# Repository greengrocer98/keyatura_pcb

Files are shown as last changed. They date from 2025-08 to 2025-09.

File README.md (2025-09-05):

# KEYATURA
Keyatura (/ˌkeɪ.əˈtʊə.rə/) - 36-key ergonomic keyboard with MX-spacing and support of choc_v2v1/MX switches.

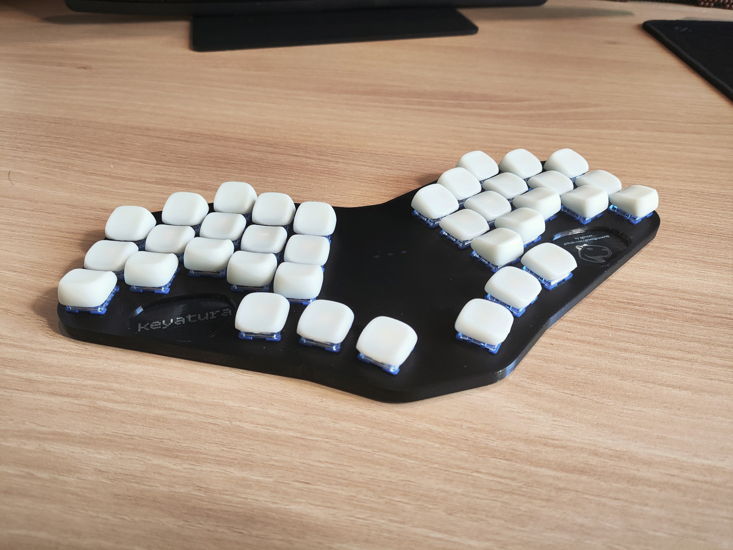
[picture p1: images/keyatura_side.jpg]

### Features
* Promicro compatible MCU
* Hotswap for choc/MX
* Three led indicators
* Mill-Max hotswap sockets for MCU
* Power switch
* Reset button
### PCB
#### <div align="center">Top<div>
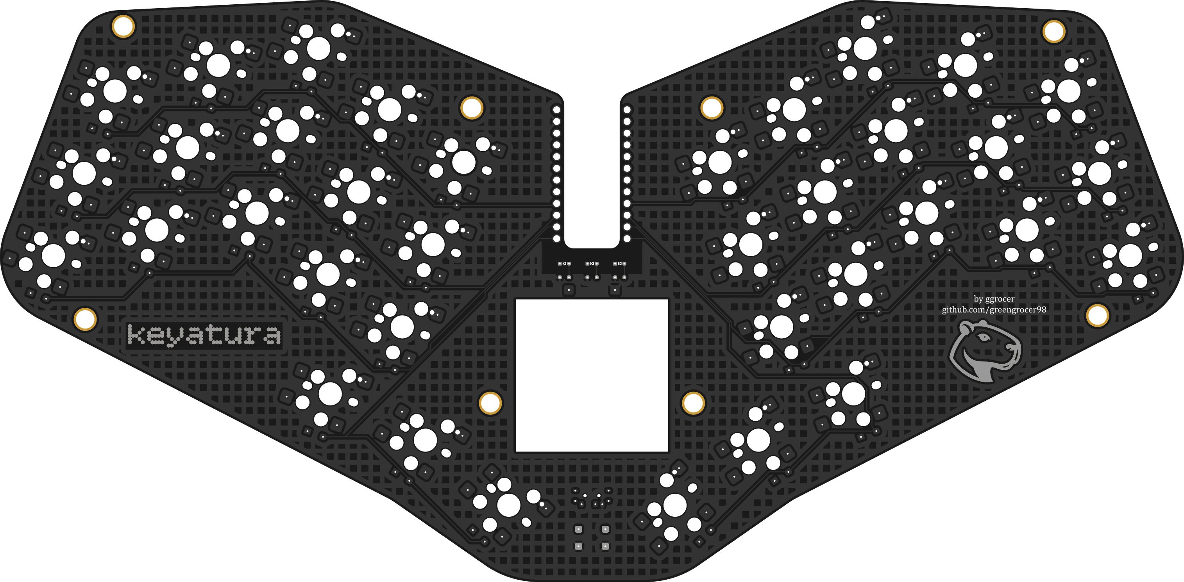
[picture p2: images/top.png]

#### <div align="center">Bottom<div>
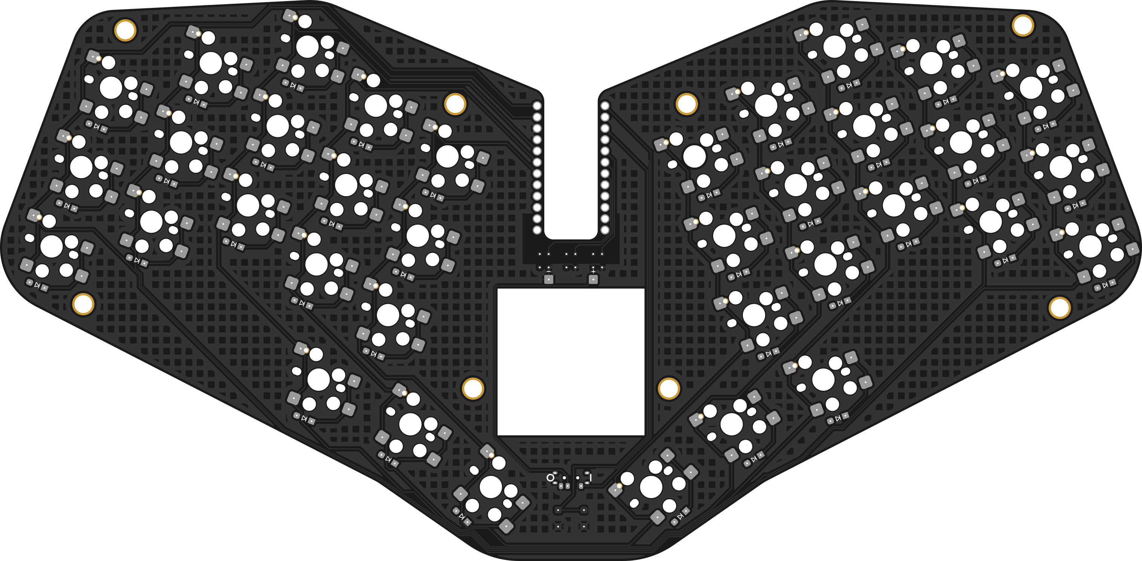
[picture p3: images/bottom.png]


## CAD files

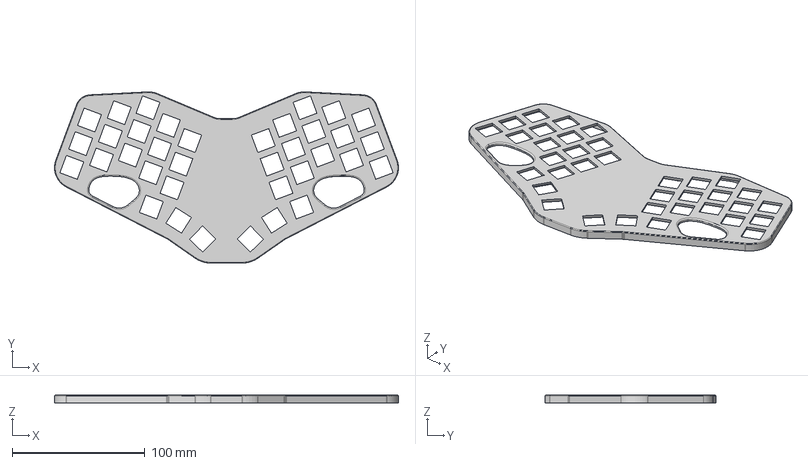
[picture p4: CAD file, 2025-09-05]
3d files/top plate.step
259.5 x 129.2 x 5.80 mm

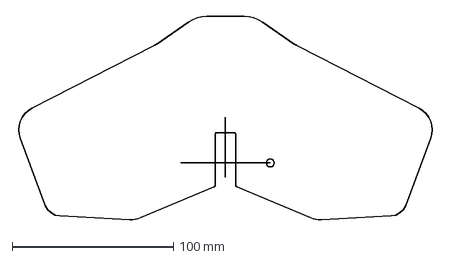
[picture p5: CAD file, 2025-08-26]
kicad/keyatura/outline_v2.dxf
259.9 x 126.3 mm

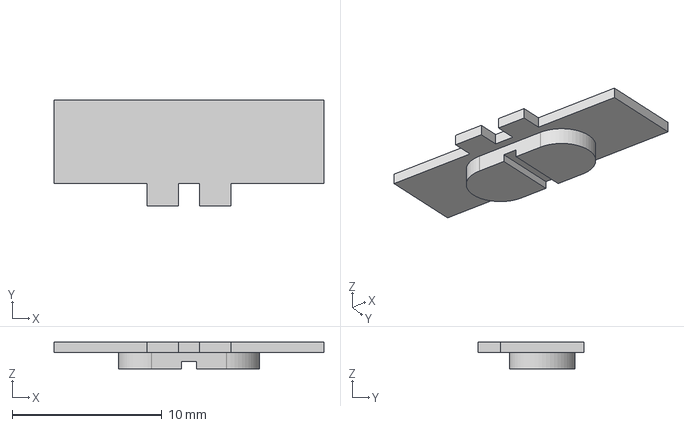
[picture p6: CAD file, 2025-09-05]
3d files/switch slicer.step
18.0 x 7.10 x 1.80 mm

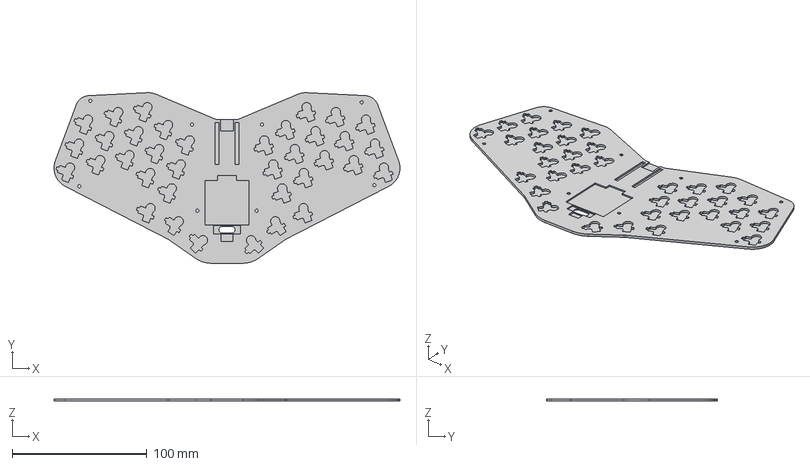
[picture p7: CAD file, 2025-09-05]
3d files/bottom plate.step
257.2 x 126.9 x 1.80 mm

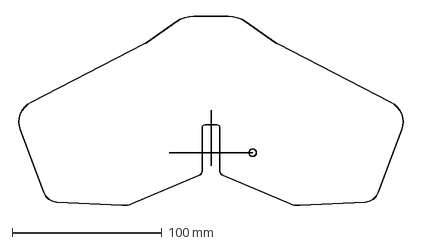
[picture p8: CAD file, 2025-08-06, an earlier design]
kicad/keyatura/outline.dxf
259.9 x 126.3 mm

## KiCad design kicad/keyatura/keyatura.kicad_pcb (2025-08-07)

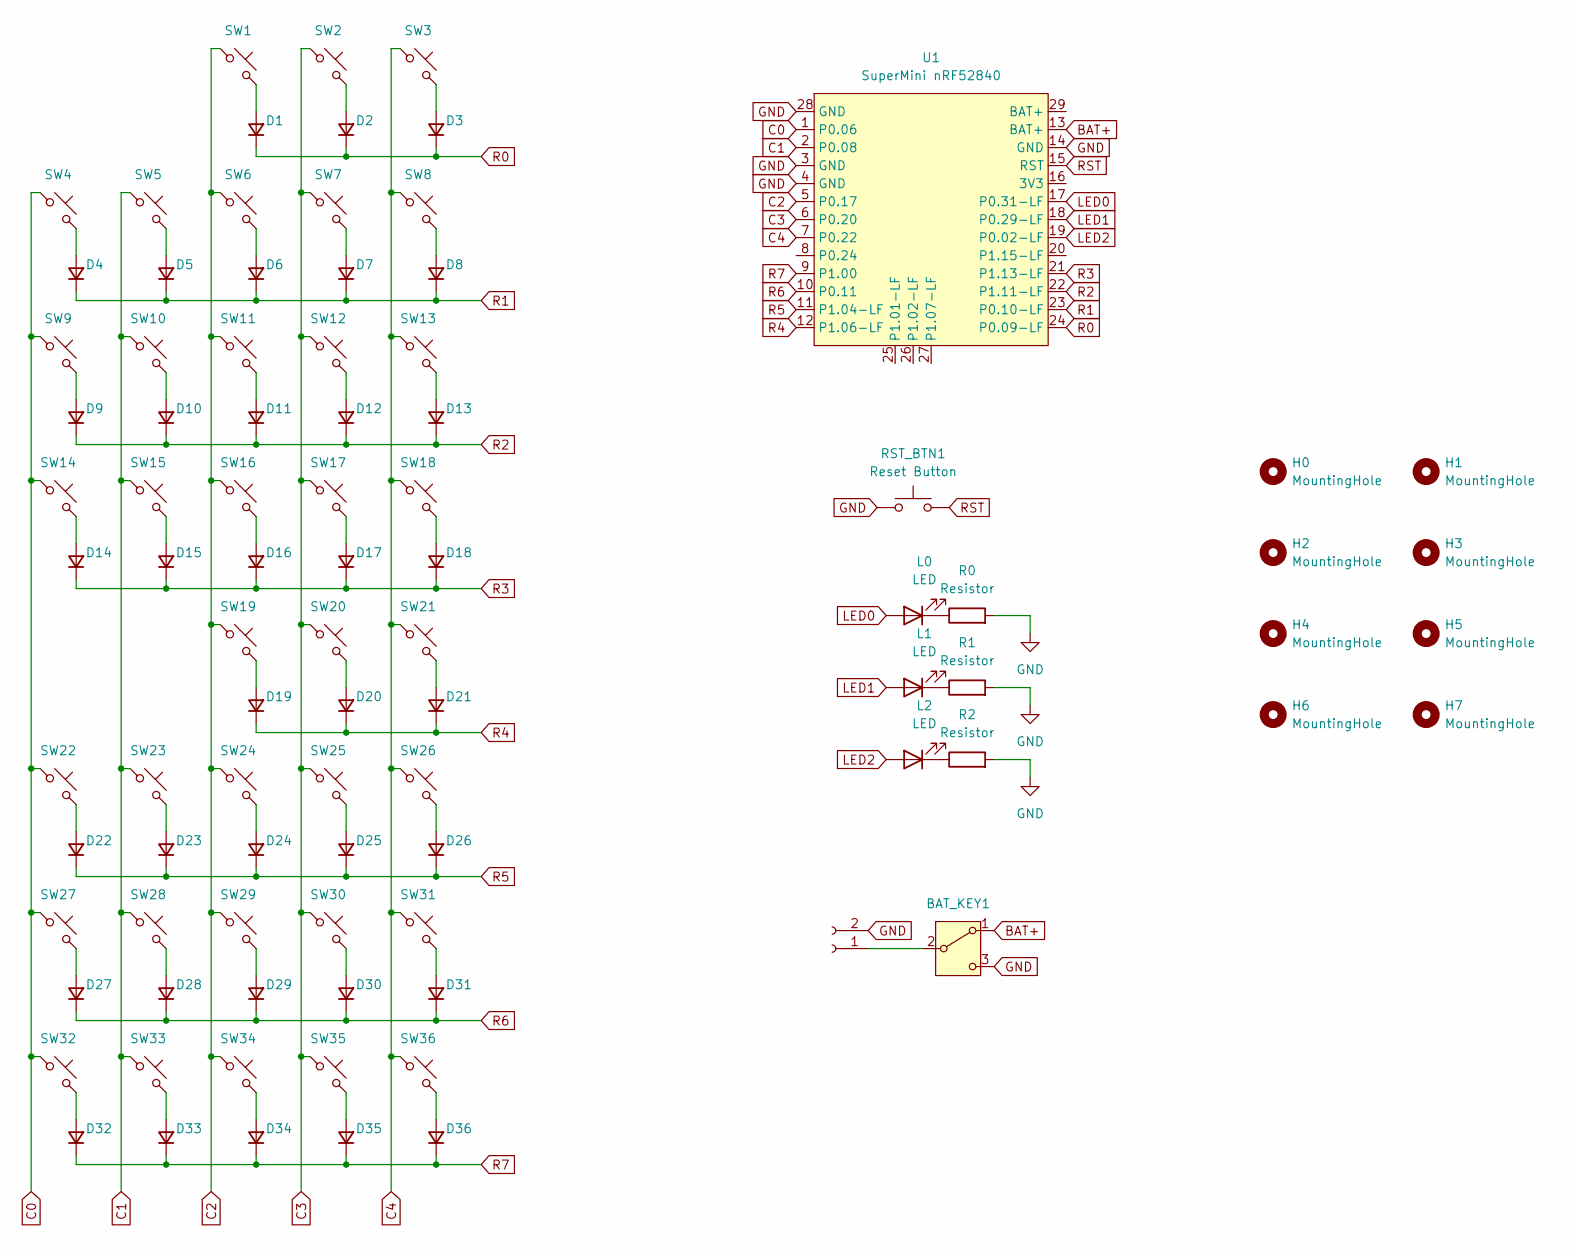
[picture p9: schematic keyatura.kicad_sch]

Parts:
BAT_KEY1: SW_SPDT; MSK-12C02
D1, D2, D3, D4, D5, D6, D7, D8, D9, D10, D11, D12, D13, D14, D15, D16, D17, D18, D19, D20, D21, D22, D23, D24, D25, D26, D27, D28, D29, D30, D31, D32, D33, D34, D35, D36: D; diode
H0, H1, H2, H3, H4, H5, H6, H7: MountingHole; mounting hole
J1: Battery; battery
L0, L1, L2: LED
R0, R1, R2: Resistor; resistor
RST_BTN1: Reset Button; reset button
SW1, SW2, SW3, SW4, SW5, SW6, SW7, SW8, SW9, SW10, SW11, SW12, SW13, SW14, SW15, SW16, SW17, SW18, SW19, SW20, SW21, SW22, SW23, SW24, SW25, SW26, SW27, SW28, SW29, SW30, SW31, SW32, SW33, SW34, SW35, SW36: SW_Push; SW_MX_Kailh_Choc_V1V2_HotSwap_Hybrid
U1: SuperMini nRF52840; supermini

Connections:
BAT+: BAT_KEY1.1 (A), U1.13 (BAT+)
C0: SW4.1, SW9.1, SW14.1, SW22.1, SW27.1, SW32.1, U1.1 (P0.06)
C1: SW5.1, SW10.1, SW15.1, SW23.1, SW28.1, SW33.1, U1.2 (P0.08)
C2: SW1.1, SW6.1, SW11.1, SW16.1, SW19.1, SW24.1, SW29.1, SW34.1, U1.5 (P0.17)
C3: SW2.1, SW7.1, SW12.1, SW17.1, SW20.1, SW25.1, SW30.1, SW35.1, U1.6 (P0.20)
C4: SW3.1, SW8.1, SW13.1, SW18.1, SW21.1, SW26.1, SW31.1, SW36.1, U1.7 (P0.22)
GND: BAT_KEY1.3 (C), J1.2, R0.2, R1.2, R2.2, RST_BTN1.1, U1.3 (GND), U1.4 (GND), U1.14 (GND), U1.28 (GND)
LED0: L0.2 (A), U1.17 (P0.31-LF)
LED1: L1.2 (A), U1.18 (P0.29-LF)
LED2: L2.2 (A), U1.19 (P0.02-LF)
unnamed: BAT_KEY1.2 (B), J1.1
unnamed: D1.2 (A), SW1.2
unnamed: D2.2 (A), SW2.2
unnamed: D3.2 (A), SW3.2
unnamed: D4.2 (A), SW4.2
unnamed: D5.2 (A), SW5.2
unnamed: D6.2 (A), SW6.2
unnamed: D7.2 (A), SW7.2
unnamed: D8.2 (A), SW8.2
unnamed: D9.2 (A), SW9.2
unnamed: D10.2 (A), SW10.2
unnamed: D11.2 (A), SW11.2
unnamed: D12.2 (A), SW12.2
unnamed: D13.2 (A), SW13.2
unnamed: D14.2 (A), SW14.2
unnamed: D15.2 (A), SW15.2
unnamed: D16.2 (A), SW16.2
unnamed: D17.2 (A), SW17.2
unnamed: D18.2 (A), SW18.2
unnamed: D19.2 (A), SW19.2
unnamed: D20.2 (A), SW20.2
unnamed: D21.2 (A), SW21.2
unnamed: D22.2 (A), SW22.2
unnamed: D23.2 (A), SW23.2
unnamed: D24.2 (A), SW24.2
unnamed: D25.2 (A), SW25.2
unnamed: D26.2 (A), SW26.2
unnamed: D27.2 (A), SW27.2
unnamed: D28.2 (A), SW28.2
unnamed: D29.2 (A), SW29.2
unnamed: D30.2 (A), SW30.2
unnamed: D31.2 (A), SW31.2
unnamed: D32.2 (A), SW32.2
unnamed: D33.2 (A), SW33.2
unnamed: D34.2 (A), SW34.2
unnamed: D35.2 (A), SW35.2
unnamed: D36.2 (A), SW36.2
unnamed: L0.1 (K), R0.1
unnamed: L1.1 (K), R1.1
unnamed: L2.1 (K), R2.1
R0: D1.1 (K), D2.1 (K), D3.1 (K), U1.24 (P0.09-LF)
R1: D4.1 (K), D5.1 (K), D6.1 (K), D7.1 (K), D8.1 (K), U1.23 (P0.10-LF)
R2: D9.1 (K), D10.1 (K), D11.1 (K), D12.1 (K), D13.1 (K), U1.22 (P1.11-LF)
R3: D14.1 (K), D15.1 (K), D16.1 (K), D17.1 (K), D18.1 (K), U1.21 (P1.13-LF)
R4: D19.1 (K), D20.1 (K), D21.1 (K), U1.12 (P1.06-LF)
R5: D22.1 (K), D23.1 (K), D24.1 (K), D25.1 (K), D26.1 (K), U1.11 (P1.04-LF)
R6: D27.1 (K), D28.1 (K), D29.1 (K), D30.1 (K), D31.1 (K), U1.10 (P0.11)
R7: D32.1 (K), D33.1 (K), D34.1 (K), D35.1 (K), D36.1 (K), U1.9 (P1.00)
RST: RST_BTN1.2, U1.15 (RST)

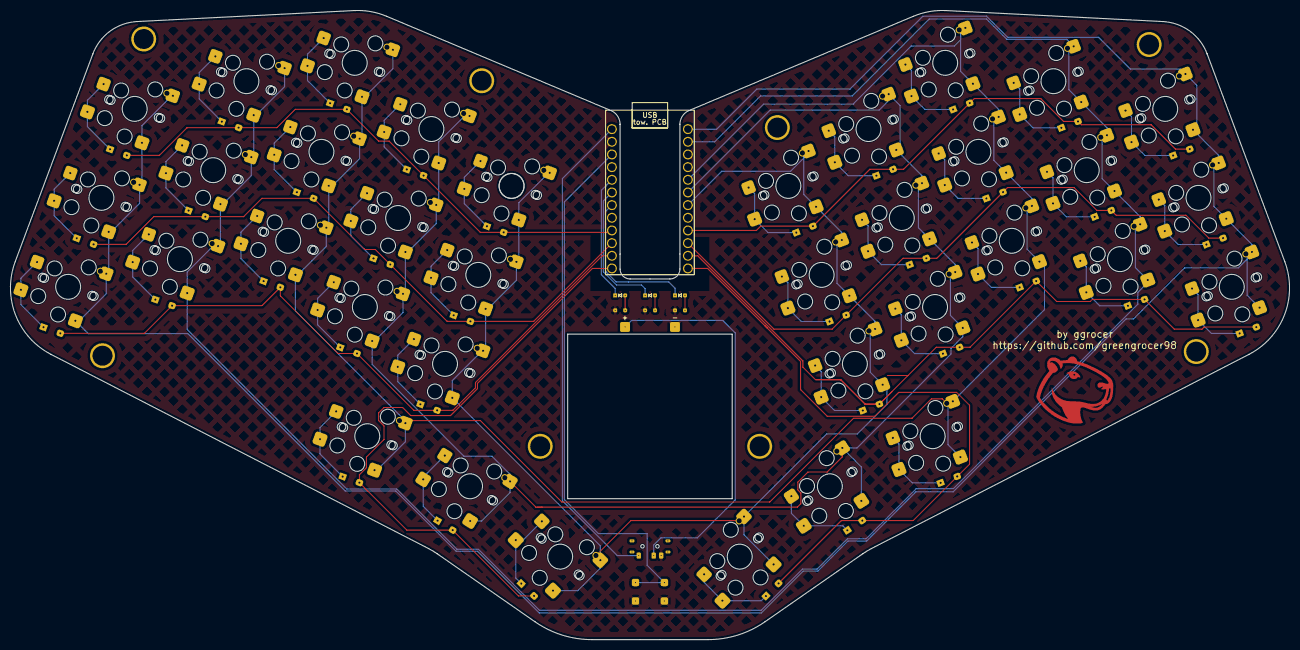
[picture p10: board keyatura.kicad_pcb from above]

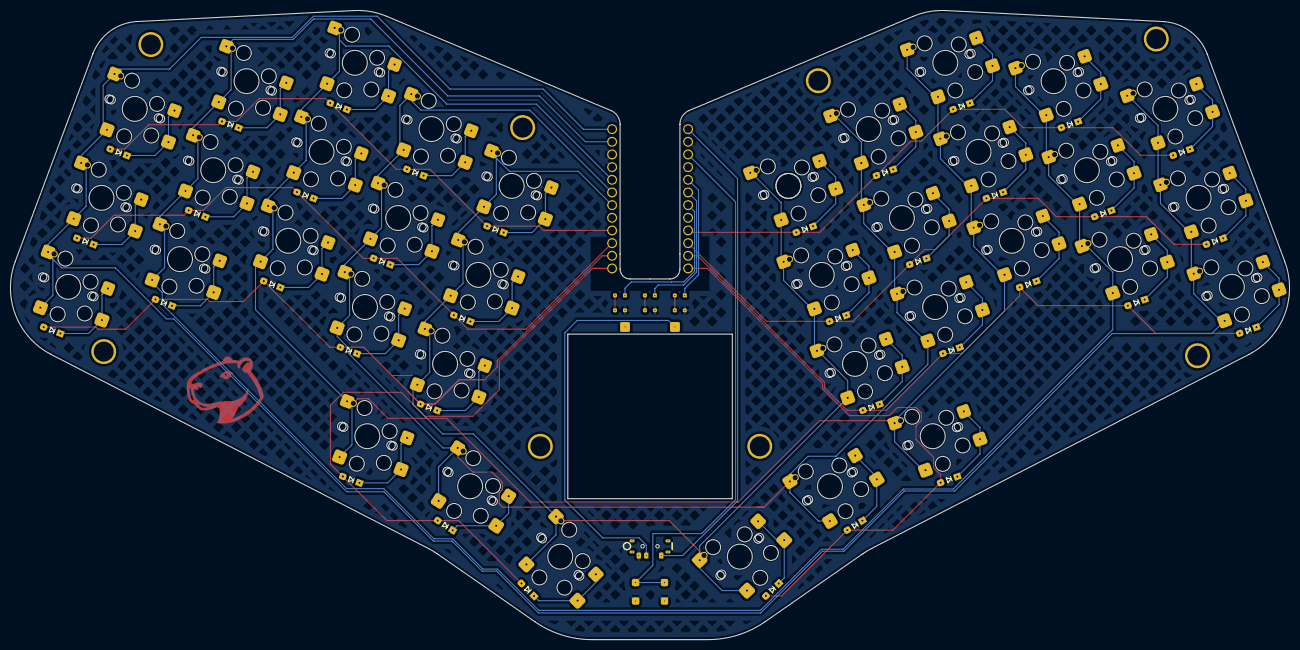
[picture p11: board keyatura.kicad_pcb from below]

Board: 2 copper layers, 256.5 x 126.2 mm, 90 parts (37 on the bottom side), 59 nets.

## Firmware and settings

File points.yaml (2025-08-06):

matrix_pinky_bottom:
    x: 0
    'y': 0
    r: -20.5
    meta:
        stagger: 0
        spread: 19.05
        splay: 0
        origin:
            - 0
            - 0
        orient: 0
        shift:
            - 0
            - 0
        rotate: 0
        adjust: {}
        width: 18
        height: 18
        padding: 19.05
        autobind: 10
        skip: false
        asym: both
        colrow: pinky_bottom
        name: matrix_pinky_bottom
        column_net: C0
        row_net: R1
        mirror:
            row_net: R5
        zone: &ref_1
            key:
                padding: px
                spread: py
            columns:
                pinky: &ref_0
                    key:
                        column_net: C0
                    rows: {}
                    name: pinky
                ring: &ref_2
                    key:
                        stagger: px-6
                        column_net: C1
                    rows: {}
                    name: ring
                middle: &ref_3
                    key:
                        stagger: px-8
                        column_net: C2
                    rows: {}
                    name: middle
                index: &ref_4
                    key:
                        stagger: '-(px-12)'
                        column_net: C3
                    rows: {}
                    name: index
                inner: &ref_5
                    key:
                        stagger: '-(px-14)'
                        column_net: C4
                    rows: {}
                    name: inner
            rows:
                bottom:
                    row_net: R1
                    mirror:
                        row_net: R5
                home:
                    row_net: R2
                    mirror:
                        row_net: R6
                top:
                    row_net: R3
                    mirror:
                        row_net: R7
            name: matrix
        col: *ref_0
        row: bottom
        bind:
            - 10
            - 0
            - 0
            - 0
        mirrored: false
matrix_pinky_home:
    x: 6.6714506
    'y': 17.8436052
    r: -20.5
    meta:
        stagger: 0
        spread: 19.05
        splay: 0
        origin:
            - 0
            - 0
        orient: 0
        shift:
            - 0
            - 0
        rotate: 0
        adjust: {}
        width: 18
        height: 18
        padding: 19.05
        autobind: 10
        skip: false
        asym: both
        colrow: pinky_home
        name: matrix_pinky_home
        column_net: C0
        row_net: R2
        mirror:
            row_net: R6
        zone: *ref_1
        col: *ref_0
        row: home
        bind:
            - 10
            - 10
            - 10
            - 0
        mirrored: false
matrix_pinky_top:
    x: 13.3429012
    'y': 35.6872104
    r: -20.5
    meta:
        stagger: 0
        spread: 19.05
        splay: 0
        origin:
            - 0
            - 0
        orient: 0
        shift:
            - 0
            - 0
        rotate: 0
        adjust: {}
        width: 18
        height: 18
        padding: 19.05
        autobind: 10
        skip: false
        asym: both
        colrow: pinky_top
        name: matrix_pinky_top
        column_net: C0
        row_net: R3
        mirror:
            row_net: R7
        zone: *ref_1
        col: *ref_0
        row: top
        bind:
            - 0
            - 10
            - 10
            - 0
        mirrored: false
matrix_ring_bottom:
    x: 22.4138115
    'y': 5.5521215
    r: -20.5
    meta:
        stagger: 13.05
        spread: 19.05
        splay: 0
        origin:
            - 0
            - 0
        orient: 0
        shift:
            - 0
            - 0
        rotate: 0
        adjust: {}
        width: 18
        height: 18
        padding: 19.05
        autobind: 10
        skip: false
        asym: both
        colrow: ring_bottom
        name: matrix_ring_bottom
        column_net: C1
        row_net: R1
        mirror:
            row_net: R5
        zone: *ref_1
        col: *ref_2
        row: bottom
        bind:
            - 10
            - 0
            - 0
            - 10
        mirrored: false
matrix_ring_home:
    x: 29.0852621
    'y': 23.3957267
    r: -20.5
    meta:
        stagger: 13.05
        spread: 19.05
        splay: 0
        origin:
            - 0
            - 0
        orient: 0
        shift:
            - 0
            - 0
        rotate: 0
        adjust: {}
        width: 18
        height: 18
        padding: 19.05
        autobind: 10
        skip: false
        asym: both
        colrow: ring_home
        name: matrix_ring_home
        column_net: C1
        row_net: R2
        mirror:
            row_net: R6
        zone: *ref_1
        col: *ref_2
        row: home
        bind:
            - 10
            - 10
            - 10
            - 10
        mirrored: false
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

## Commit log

2025-08-06 update footprint git modules
2025-08-07 added gerber files
    [keyatura-B_Cu.gbr, keyatura-B_Mask.gbr, keyatura-B_Paste.gbr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]
2025-08-11 final changes in pcb before release
    [keyatura-B_Cu.gbr, keyatura-B_Mask.gbr, keyatura-B_Paste.gbr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]
2025-08-26 fix diode footprints and outline edge cuts
    [keyatura.kicad_sch, outline_v2.dxf]
2025-09-05 added 3d files and updated README
    [bottom plate.step, switch slicer.step, top plate.step]
